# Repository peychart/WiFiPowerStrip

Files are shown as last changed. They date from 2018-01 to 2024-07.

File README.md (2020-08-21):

Wifi Power Strip
================

Software:
---------

C++ source, HTML, Javascript & JSON communication with the web interface.

* Full MQTT: configuration, status and distribution of the schema allowing a device auto-detection in home-assistant,
* Allows to control up to 6 switches per ESP8266 module,
* Also allows controlling multiple outputs with a single switch (tuya power strips),
* Can control up to 12 switches with an additional slave module connected via the serial port,
* allows timers on each output,
* management of single-switch multi-output devices(*),
* allows to disabe the timer of an output by maintaining the action of its corresponding switch for a few seconds (only during its activation in the case of multi-outputs with single-switch - see tuya power strip),
* several configurables SSID,
* high or low value configurable on each output (allowing different interface cards),
* configuration and retrieval of the device status by html requests (JSON format) also available,
* available backup of the output states on reboot,
* firmware update via WiFi (OTA), without loss of setting (except if the version number is modified beforehand),
* can manage contact sensors (with virtual outputs),
* the html interface can be delocalized to a dedicated server,
* dedug trace available in a telnet console (only in the C beta-version),
* each object (wifi manager, pins manager, mqtt or ntp manager) is reusable for other projects...

(*): pressing, for example, the switch 3 times with less than 1 second between each press activates the third output; if the switch is held (at least 3s) on the last press, the time delay (if set on the selected output) will be canceled.

Http requests available:
<table>
  <tr>
    <td><tt>http://IPAddress</tt></td>
    <td>WEB User Interface</td>
  </tr>
  <tr>
    <td><tt>http://IPAddress/status</tt></td>
    <td>get the device state in JSON format - also used by the html interface</td>
  </tr>
  <tr>
    <td><tt>http://IPAddress/status?{'JSON setting'}</tt></td>
    <td>set all or parts of the state setting (see above)</td>
  </tr>
  <tr>
    <td><tt>http://IPAddress/html</tt></td>
    <td>allows the recovery of the HTML code of the interface for the purpose of its delocalization on a dedicated external server.</td>
  </tr>
  <tr>
    <td><tt>http://IPAddress/restart</tt></td>
    <td>restart the device, the output states will be restored.</td>
  </tr>
</table>

TODO:
* set the "Access-Control-Allow-Origin" parameter (to allow a domain name use),
* test the new serial communication with the slave,
* add the trigger setting programmed in the interface,
* finalize the setting of all the mqtt parameters in the interface (default values in setting.h),
* do the dev doc,
* ...

Screenshots:

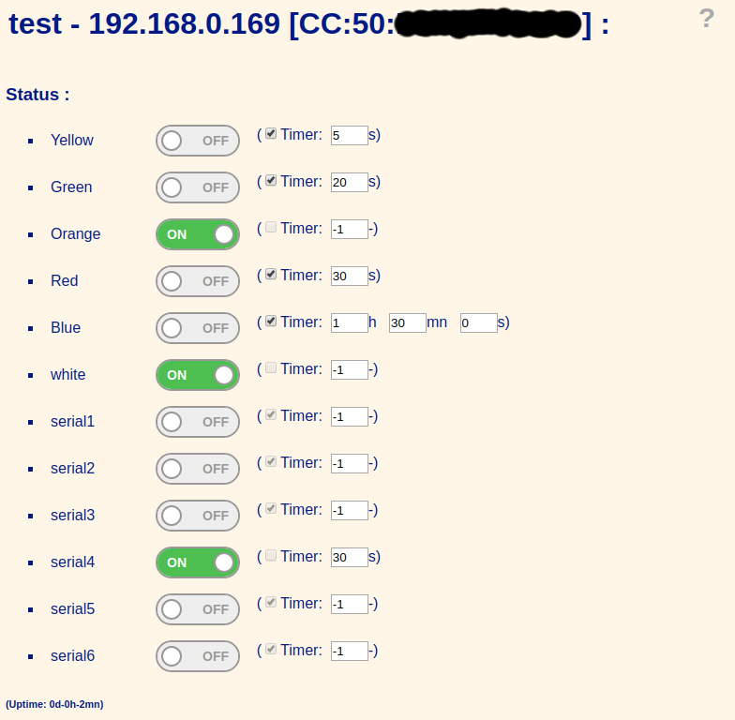
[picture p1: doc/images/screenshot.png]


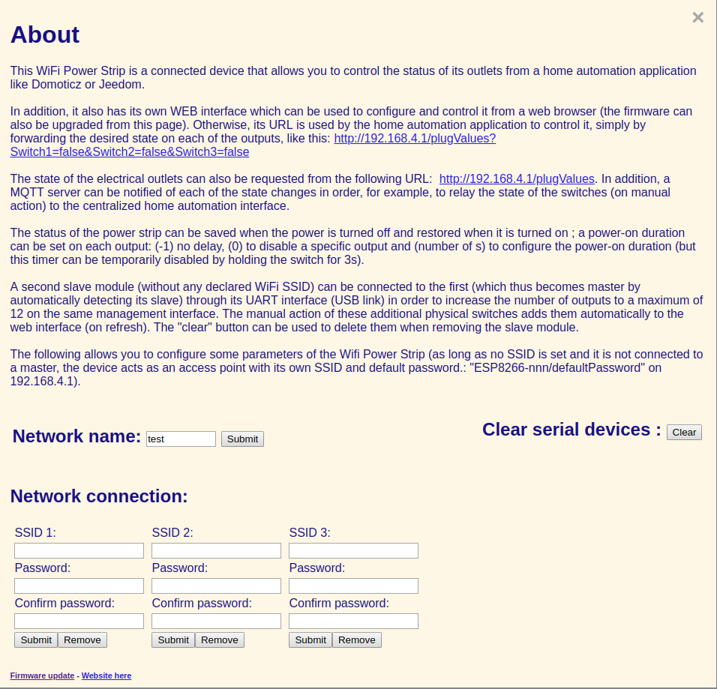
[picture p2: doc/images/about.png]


MQTT parameters:

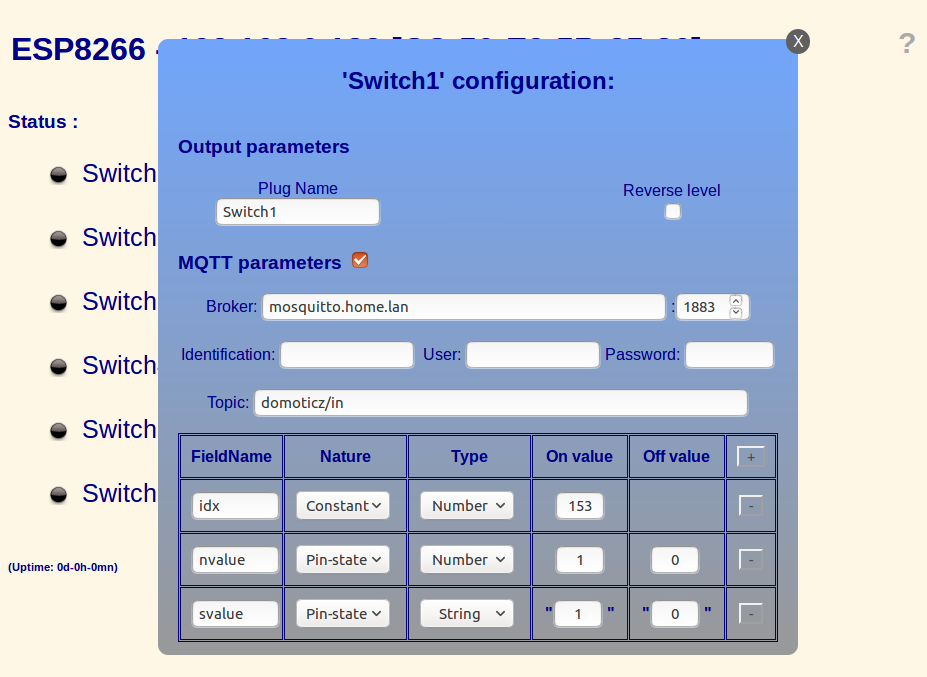
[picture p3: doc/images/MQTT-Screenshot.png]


Hardware:
---------

* Webmos D1 mini + wiring diagram of the interfaces (with 2N7002 or S8050):
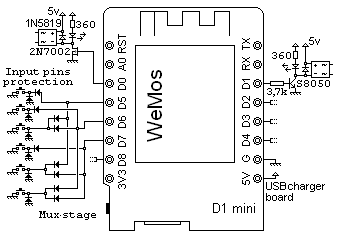
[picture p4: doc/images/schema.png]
* 
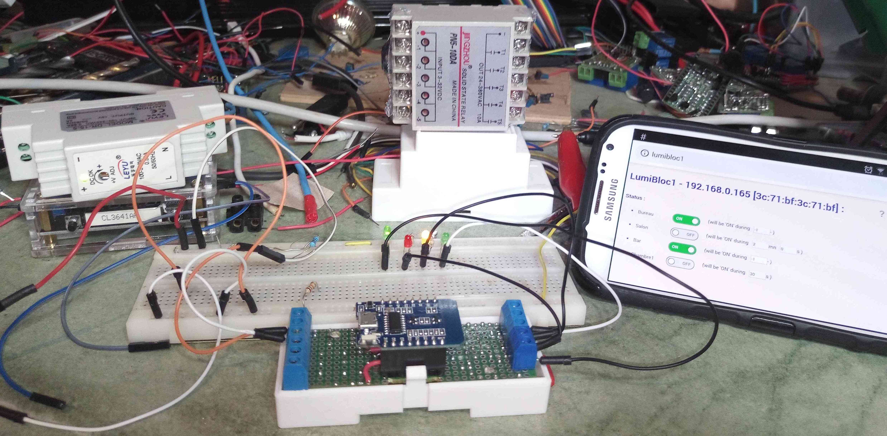
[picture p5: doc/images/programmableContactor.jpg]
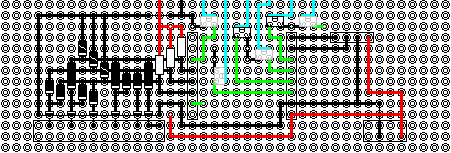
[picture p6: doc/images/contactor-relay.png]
* Progammable contactors with WiFi control:  
* Interface board: 1 x Wemos mini D1, 15 x 1N5819, 3 x Zeners 3.3v, 6 resistors 360 ohms, 6 x MOSFET 2N7002 SOT23 and somes connectors... for each master / slave module (via UART) of 6 inputs and 6 outputs for power interface control (and SSR relay interface or, best to turn off led lights: 5V relay module board, 6 channels).
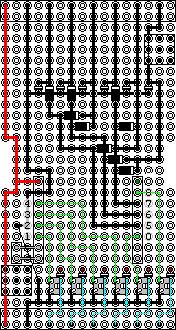
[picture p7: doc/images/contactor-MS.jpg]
* 
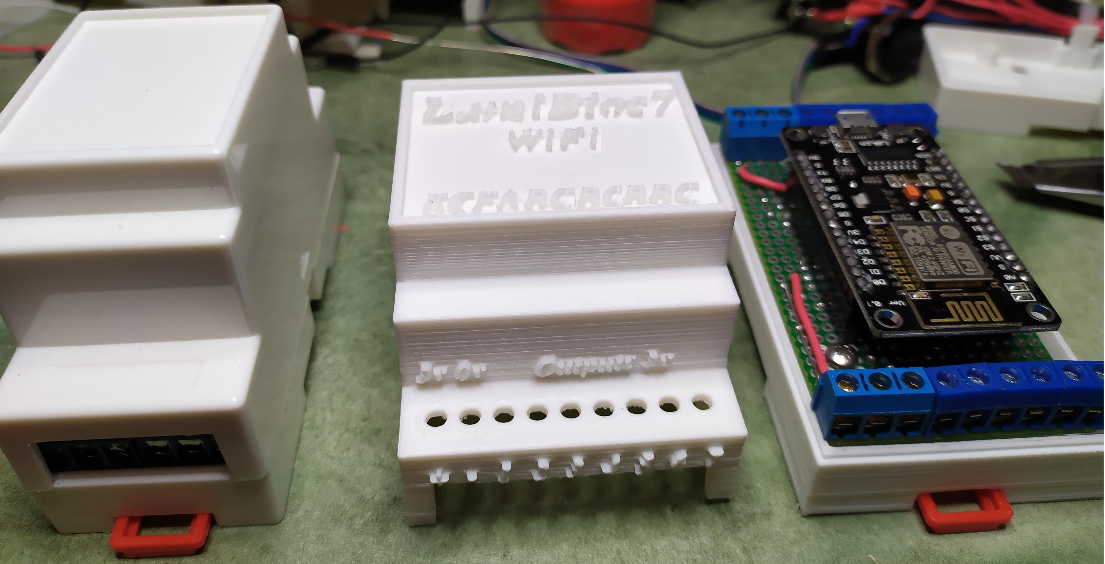
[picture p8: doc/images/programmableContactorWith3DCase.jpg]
* With 3D printed case: 
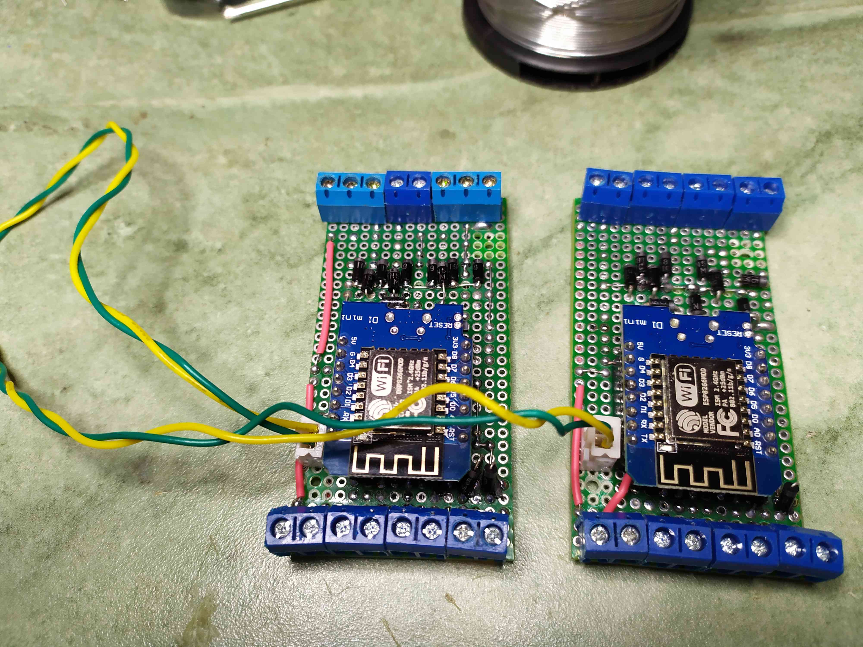
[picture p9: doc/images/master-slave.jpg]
* Master/Slave modules: 
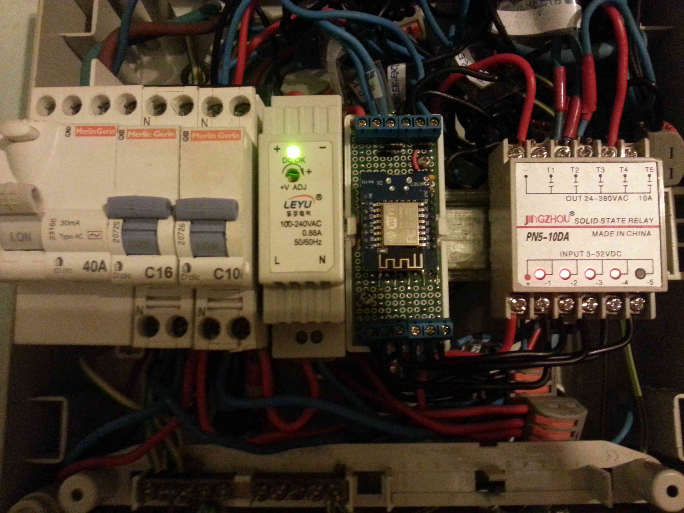
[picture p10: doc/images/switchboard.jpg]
* switchboard (5-way module for lighting control): 
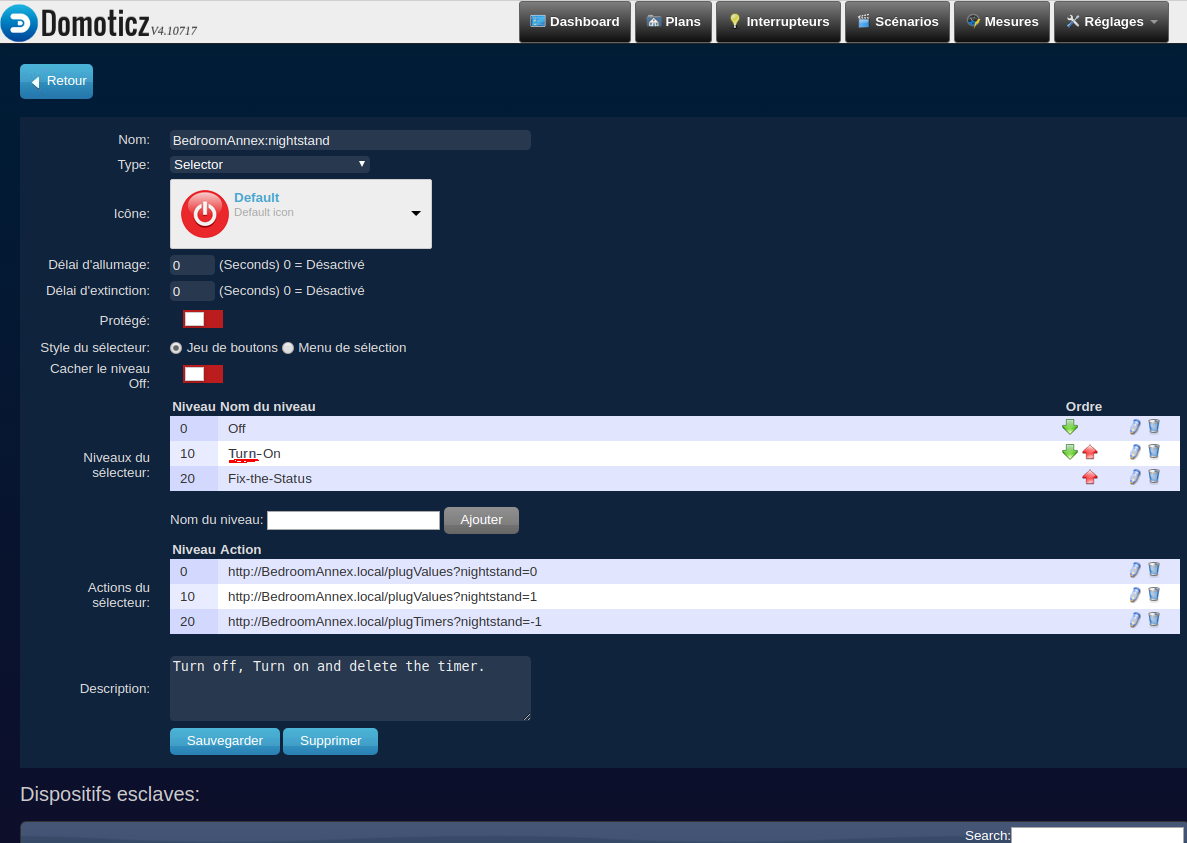
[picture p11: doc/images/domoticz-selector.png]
* Example of selector definition in Domoticz: 
* Plan view ("Fixe-the-State" to inhibit the internal timer, such a 3-second press on switch):
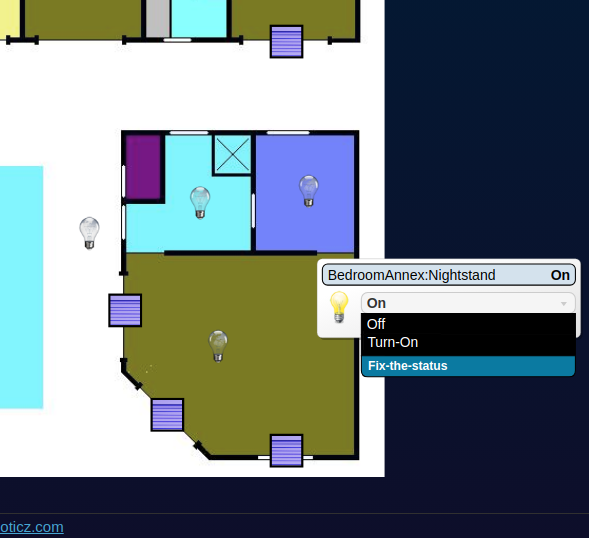
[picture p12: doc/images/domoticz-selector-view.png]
* 
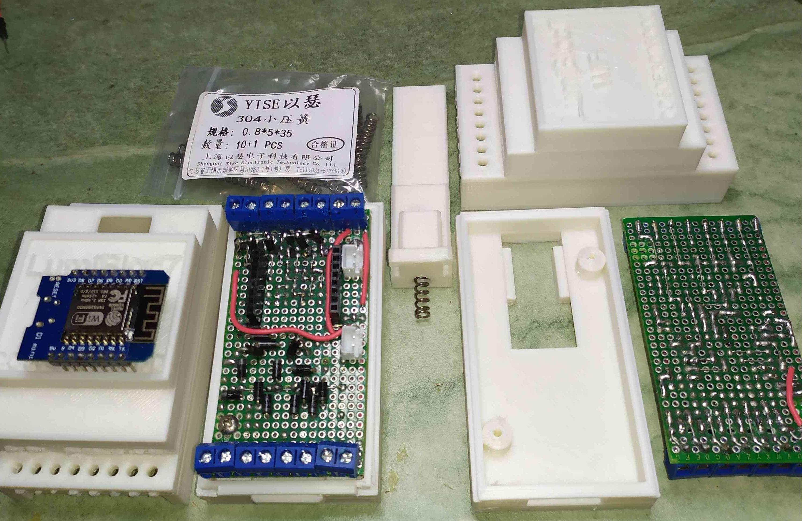
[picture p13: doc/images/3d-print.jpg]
* 

* relay modules (Serial Master/Slave):
* 

* USB WiFi-relay (same code with ESP01-1m):
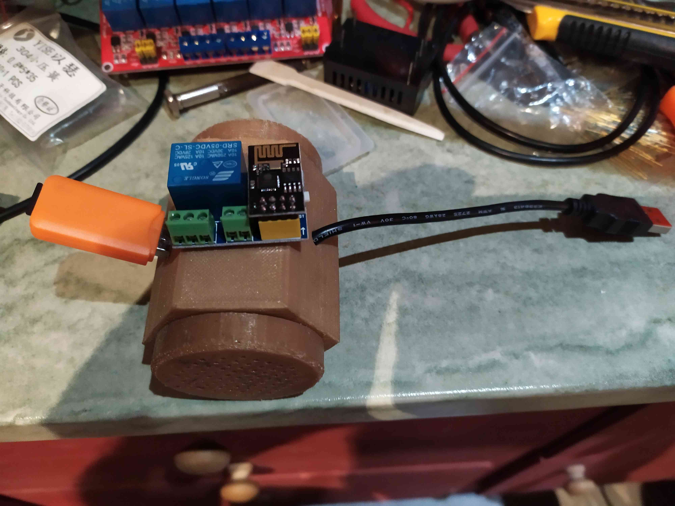
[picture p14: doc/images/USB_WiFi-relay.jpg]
* 

* Hacking - same code on TUYA power strip (TYWE3S):
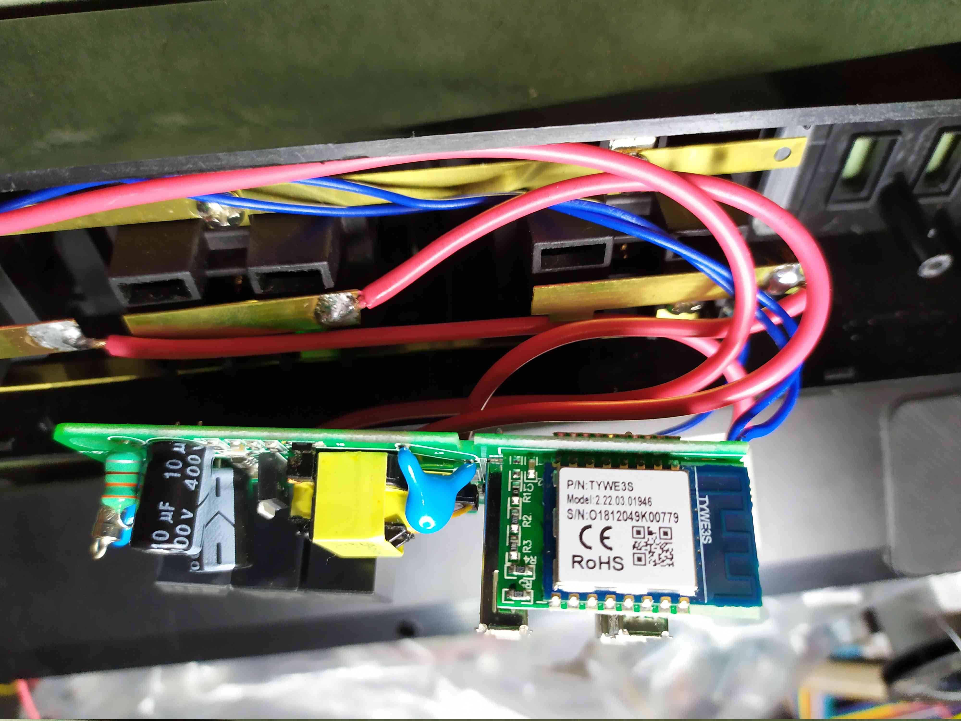
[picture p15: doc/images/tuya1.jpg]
* 
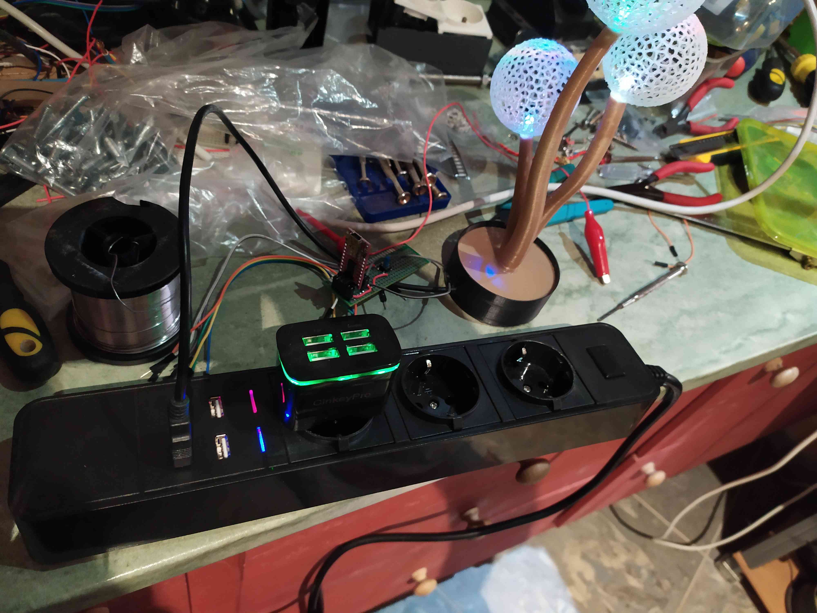
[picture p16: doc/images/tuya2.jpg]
*

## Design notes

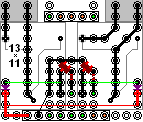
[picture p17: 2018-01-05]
doc/images/module.png

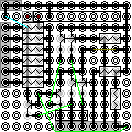
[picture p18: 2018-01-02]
doc/images/switchBoard.png

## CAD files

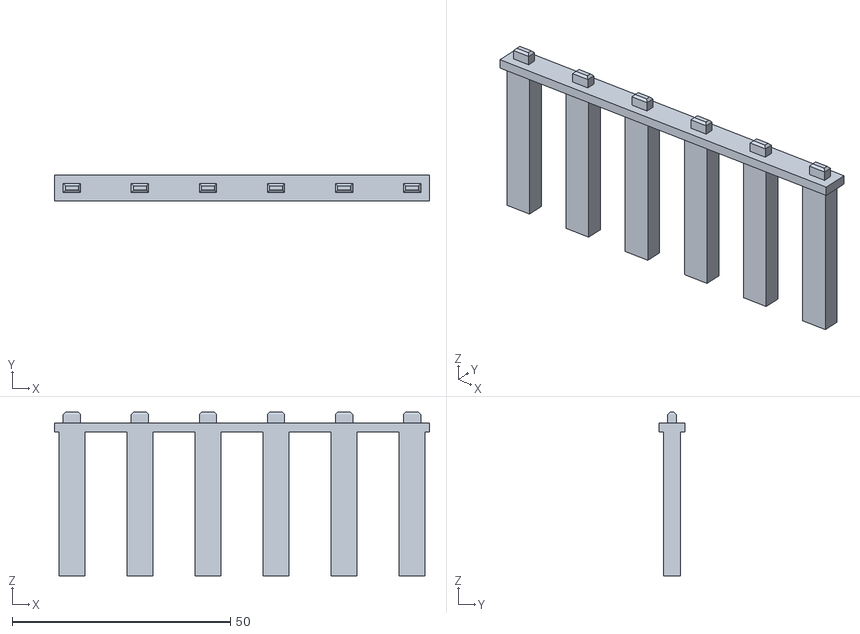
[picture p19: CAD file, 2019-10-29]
3d-templates/Contact-version/leds.stl
86.0 x 6.00 x 37.5

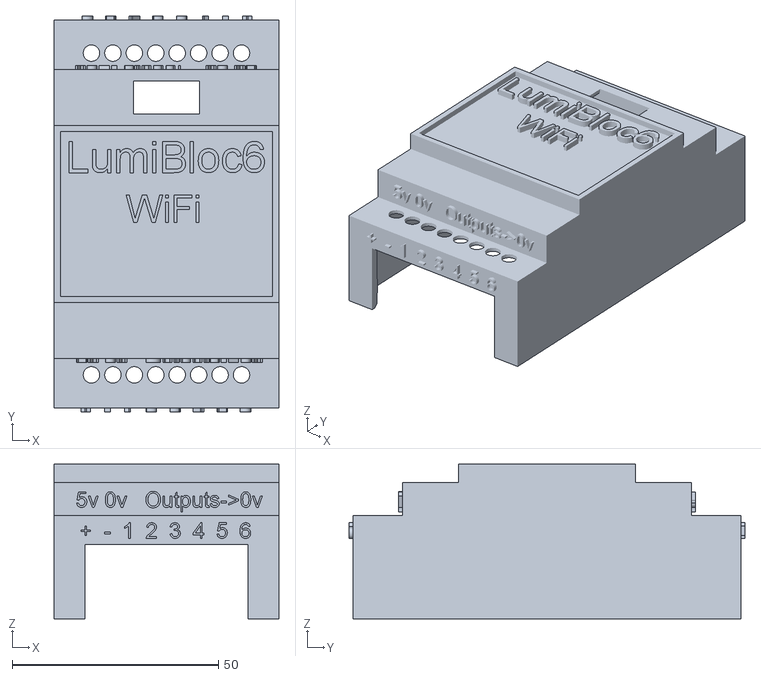
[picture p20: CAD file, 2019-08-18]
3d-templates/SSR-version/lumiCouvercle.stl
54.5 x 96.0 x 37.5

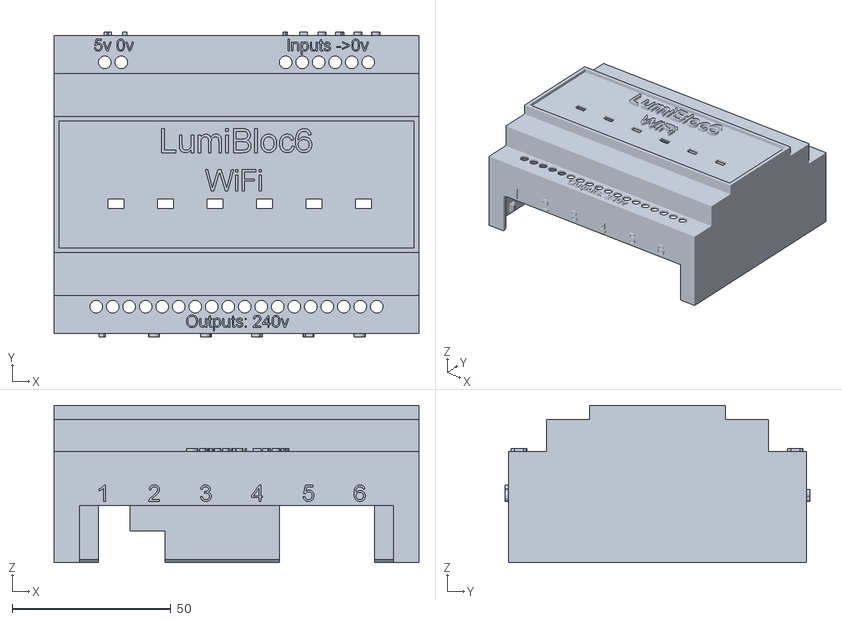
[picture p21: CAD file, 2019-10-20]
3d-templates/Contact-version/relayLid.stl
115.0 x 96.0 x 49.5

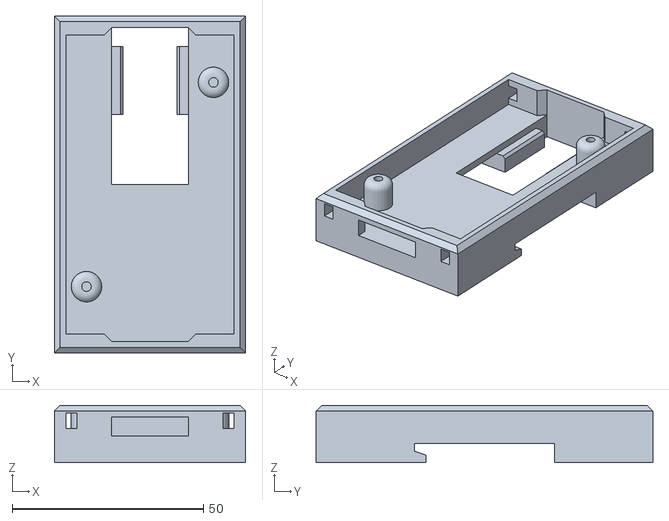
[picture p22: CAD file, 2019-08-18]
3d-templates/SSR-version/lumiBoitier.stl
50.0 x 88.0 x 15.0

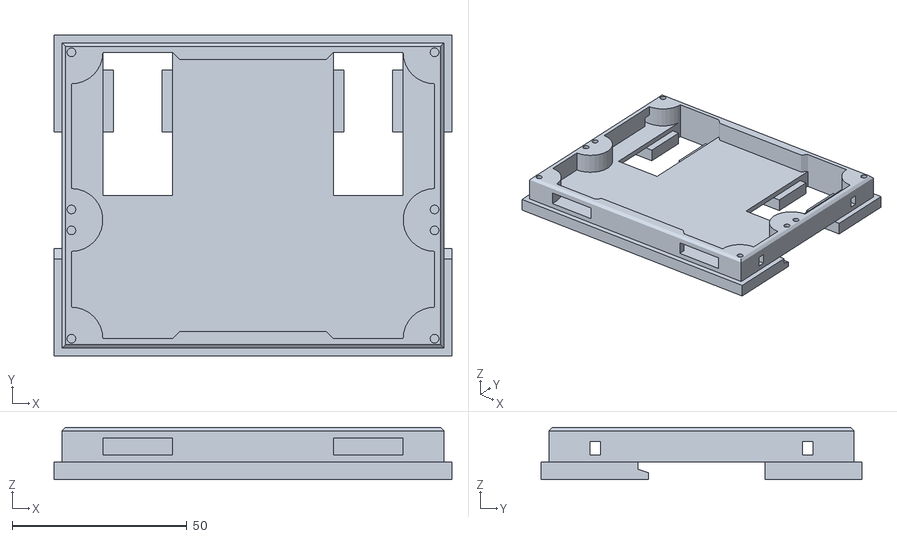
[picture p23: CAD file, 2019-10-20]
3d-templates/Contact-version/relayBox.stl
114.0 x 92.0 x 15.0

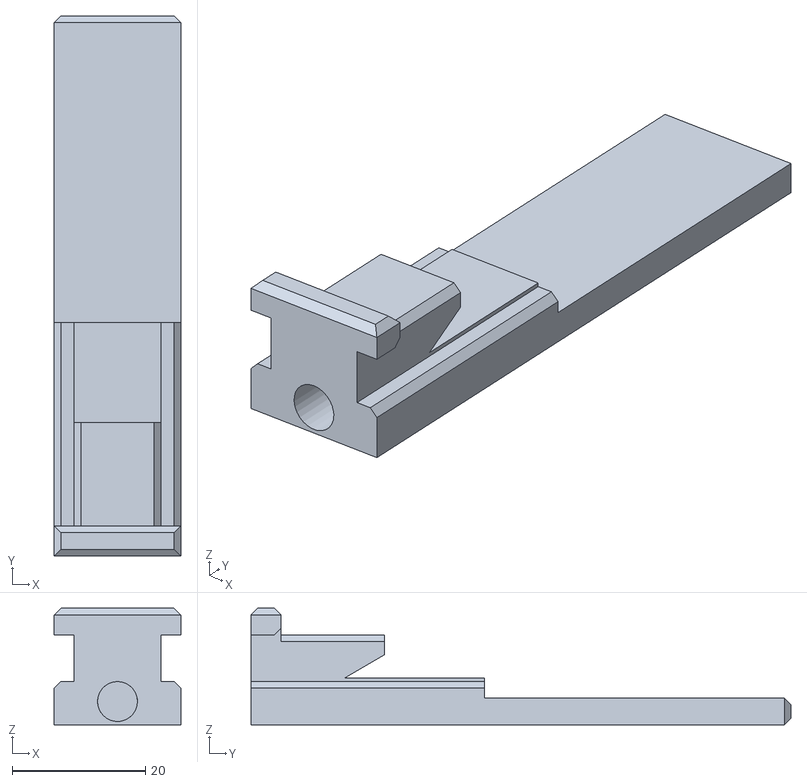
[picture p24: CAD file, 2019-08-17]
3d-templates/SSR-version/lumiCoulisseau.stl
19.0 x 81.0 x 17.5

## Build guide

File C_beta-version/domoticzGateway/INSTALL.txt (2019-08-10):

#!/bin/bash
#This NodeJs application use this lib: http://wiki.sandaysoft.com/a/SteelSeries_Gauges
sudo apt-get update
sudo apt-get upgrade -y
sudo apt-get install -y git wget curl

# Nodejs installation:
sudo wget -O - https://raw.githubusercontent.com/audstanley/NodeJs-Raspberry-Pi/master/Install-Node.sh | bash; node -v;
sudo npm install npm@latest -g

mkdir -p /var/www/domoticzGateway
cd /var/www/domoticzGateway
wget https://raw.githubusercontent.com/peychart/WiFiPowerStrip/master/domoticzGateway/domoticzGateway.js
wget https://raw.githubusercontent.com/peychart/WiFiPowerStrip/master/domoticzGateway/domoticzGateway.service
wget https://raw.githubusercontent.com/peychart/WiFiPowerStrip/master/domoticzGateway/package.json

ln -s /usr/local/bin/node /usr/local/bin/nodejs
sudo npm install
sudo mv domoticzGateway.service /lib/systemd/system
sudo systemctl enable domoticzGateway
sudo systemctl start domoticzGateway

netstat -ant

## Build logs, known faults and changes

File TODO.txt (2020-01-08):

* end of MQTT conf pop-up,
* readConfig()/writeConfig() debugging,
* script configuration encryption,
* serial pins,
* ...

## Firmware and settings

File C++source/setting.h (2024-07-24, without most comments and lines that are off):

#define HEADER_FB360A2A9706121
#define VERSION                  "4.0.0"              //Change this value to reset current config on the next boot...
#define DEFAULTHOSTNAME          "ESP8266"
#define DEFAULTWIFIPASS          "defaultPassword"
#define WIFI_MEMORY_LEAKS         10000UL
#define DEBOUNCE_TIME             25UL                //(ms) <- switches treatments...
#define POST_DEBOUNCE_TIME        500UL               //(ms) <- very bad switches...
#define HOLD_TO_DISABLE_TIMER     3UL                 //(s)  <- switches treatments...
#define CMD_COMPLETED_TIMER       1UL                 //(s)  <- One switch/multi-outputs treatment...
#define ROUTE_VERSION              "version"
#define ROUTE_HOSTNAME             "hostname"
#define ROUTE__DEFAULT_HOSTNAME    "defHName"
#define ROUTE__DEFAULT_PASSWORD    "defWFPwd"
#define ROUTE_CHIP_IDENT           "ident"
#define ROUTE_UPTIME               "uptime"
#define ROUTE_MAC_ADDR             "macAddr"
#define ROUTE_IP_ADDR              "ip"
#define ROUTE_PIN_GPIO             "gpio"
#define ROUTE_PIN_NAME             "name"
#define ROUTE_PIN_STATE            "state"
#define ROUTE_PIN_CMD              "cmd"
#define ROUTE_PIN_VALUE            "timeout"
#define ROUTE_PIN_RESTART          "pinrestart"
#define ROUTE_PIN_ENABLED          "enabled"
#define ROUTE_PIN_MODE             "mode"
#define ROUTE_PIN_REVERSE          "reverse"
#define ROUTE_PIN_HIDDEN           "hidden"
#define ROUTE_PIN_BLINKING         "blinking"
#define ROUTE_PIN_BLINKING_UP      "blinkingUp"
#define ROUTE_PIN_BLINKING_DOWN    "blinkingDown"
#define ROUTE_WIFI_SSID            "ssid"
#define ROUTE_WIFI_PWD             "pwd"
#define ROUTE_NTP_SOURCE           "ntpSource"
#define ROUTE_NTP_ZONE             "ntpZone"
#define ROUTE_NTP_DAYLIGHT         "ntpDayLight"
#define ROUTE_MQTT_BROKER          "mqttBroker"
#define ROUTE_MQTT_PORT            "mqttPort"
#define ROUTE_MQTT_IDENT           "mqttIdent"
#define ROUTE_MQTT_USER            "mqttUser"
#define ROUTE_MQTT_PWD             "mqttPwd"
#define ROUTE_MQTT_PUBTOPIC        "mqttPubTopic"
#define ROUTE_MQTT_SCHEMA          "mqttSchema"
#define ROUTE_HTML_CODE            "html"
#define ROUTE_RESET                "reset"
#define ROUTE_RESTORE              "restoreStateOnBoot"
#define STDSTR(i)                   std::string(String(i,DEC).c_str())
#define G(n)                        String(F(n)).c_str()
#define DEFAULT_MQTT_BROKER        "192.168.0.253"
  #define DEFAULT_MQTT_PORT         1883
  #define DEFAULT_MQTT_IDENT       ""    // WARNING: must be different between devices on a same broker...
  #define DEFAULT_MQTT_USER        ""
  #define DEFAULT_MQTT_PWD         ""
  #define DEFAULT_MQTT_STATE_TOPIC (String(F("home-assistant/")) + String(ESP.getChipId(),DEC) + G("/") + ROUTE_PIN_STATE).c_str()
  #define DEFAULT_MQTT_CMD_TOPIC   (String(F("home-assistant/")) + String(ESP.getChipId(),DEC) + G("/") + ROUTE_PIN_CMD  ).c_str()
  #define MQTT_CONFIG_TOPIC        "config"
  #define PAYLOAD_ON               "on"
  #define PAYLOAD_OFF              "off"
  #define MQTT_SCHEMA(i)            std::map<std::string,untyped>{                                                 \
                                      {"state_topic"  , DEFAULT_MQTT_STATE_TOPIC + STDSTR(i) + G("/" ROUTE_PIN_STATE)  }  \
                                     ,{"command_topic", myMqtt.ident() + STDSTR(i) + G("/" ROUTE_PIN_CMD) }        \
                                     ,{"payload_on"   , G(PAYLOAD_ON)  }                                           \
                                     ,{"payload_off"  , G(PAYLOAD_OFF) }                                           \
                                     ,{"mame"         , myPins(i).name() }                                         \
                                     ,{"retain"       , false }                                                    \
                                     ,{"optimistic"   , false }                                                    \
                                     ,{"device_class" , G(ROUTE_PIN_CMD) }                                      \
                                    }
#ifdef _MAIN_
#define LUMIBLOC_RELAY6X_D1MINI
#ifdef LUMIBLOC_RELAY6X_D1MINI                                                    //relay 6x
#define INPUT_CONFIG F("[\
/*D5*/{\"14\": {\"" ROUTE_PIN_NAME "\": \"input1\" }},\
/*D6*/{\"12\": {\"" ROUTE_PIN_NAME "\": \"input2\" }},\
/*D7*/{\"13\": {\"" ROUTE_PIN_NAME "\": \"input3\" }}\
]")
#define OUTPUT_CONFIG F("[\
/*D8*/{\"15\": {\"" ROUTE_PIN_NAME "\": \"Switch1\", \"" ROUTE_PIN_REVERSE "\": false, \"" ROUTE_PIN_VALUE "\": -1, \"" ROUTE_PIN_STATE "\": false }},\
/*D1*/{ \"5\": {\"" ROUTE_PIN_NAME "\": \"Switch2\", \"" ROUTE_PIN_REVERSE "\": false, \"" ROUTE_PIN_VALUE "\": -1, \"" ROUTE_PIN_STATE "\": false }},\
/*D2*/{ \"4\": {\"" ROUTE_PIN_NAME "\": \"Switch3\", \"" ROUTE_PIN_REVERSE "\": false, \"" ROUTE_PIN_VALUE "\": -1, \"" ROUTE_PIN_STATE "\": false }},\
/*D3*/{ \"0\": {\"" ROUTE_PIN_NAME "\": \"Switch4\", \"" ROUTE_PIN_REVERSE "\": false, \"" ROUTE_PIN_VALUE "\": -1, \"" ROUTE_PIN_STATE "\": false }},\
/*D4*/{ \"2\": {\"" ROUTE_PIN_NAME "\": \"Switch5\", \"" ROUTE_PIN_REVERSE "\": false, \"" ROUTE_PIN_VALUE "\": -1, \"" ROUTE_PIN_STATE "\": false }},\
/*D0*/{\"16\": {\"" ROUTE_PIN_NAME "\": \"Switch6\", \"" ROUTE_PIN_REVERSE "\": false, \"" ROUTE_PIN_VALUE "\": -1, \"" ROUTE_PIN_STATE "\": false }}\
]")
#endif
#ifdef LUMIBLOC_SSR_D1MINI                                                        //lumibloc SSD 6x
#define INPUT_CONFIG F("[\
/*D5*/{\"14\": {\"" ROUTE_PIN_NAME "\": \"input1\" }},\
/*D6*/{\"12\": {\"" ROUTE_PIN_NAME "\": \"input2\" }},\
/*D7*/{\"13\": {\"" ROUTE_PIN_NAME "\": \"input3\" }}\
]")
#define OUTPUT_CONFIG F("[\
/*D1*/{ \"5\": {\"" ROUTE_PIN_NAME "\": \"Switch1\", \"" ROUTE_PIN_REVERSE "\": false, \"" ROUTE_PIN_VALUE "\": -1, \"" ROUTE_PIN_STATE "\": false }},\
/*D2*/{ \"4\": {\"" ROUTE_PIN_NAME "\": \"Switch2\", \"" ROUTE_PIN_REVERSE "\": false, \"" ROUTE_PIN_VALUE "\": -1, \"" ROUTE_PIN_STATE "\": false }},\
/*D3*/{ \"0\": {\"" ROUTE_PIN_NAME "\": \"Switch3\", \"" ROUTE_PIN_REVERSE "\": false, \"" ROUTE_PIN_VALUE "\": -1, \"" ROUTE_PIN_STATE "\": false }},\
/*D4*/{ \"2\": {\"" ROUTE_PIN_NAME "\": \"Switch4\", \"" ROUTE_PIN_REVERSE "\": false, \"" ROUTE_PIN_VALUE "\": -1, \"" ROUTE_PIN_STATE "\": false }},\
/*D0*/{\"16\": {\"" ROUTE_PIN_NAME "\": \"Switch5\", \"" ROUTE_PIN_REVERSE "\": false, \"" ROUTE_PIN_VALUE "\": -1, \"" ROUTE_PIN_STATE "\": false }},\
/*D8*/{\"15\": {\"" ROUTE_PIN_NAME "\": \"Switch6\", \"" ROUTE_PIN_REVERSE "\": false, \"" ROUTE_PIN_VALUE "\": -1, \"" ROUTE_PIN_STATE "\": false }}\
]")
#endif
#ifdef SIMPLESWITCH_ESP01                                                        //ESP-01S relay 1x
#define INPUT_CONFIG F("[\
/*D4*/{\"2\": { \"" ROUTE_PIN_NAME "\": \"input1\", \"mode\": INPUT_PULLUP }}\
]")
#define OUTPUT_CONFIG F("[\
/*D3*/{\"0\": {\"" ROUTE_PIN_NAME "\": \"Switch1\", \"" ROUTE_PIN_REVERSE "\": false, \"" ROUTE_PIN_VALUE "\": -1, \"" ROUTE_PIN_STATE "\": false }}\
]")
#endif
#ifdef POWERSTRIP                                                                //TUYA TYSE3S Power Strip 3x
#define INPUT_CONFIG F("[\
/*D7*/{\"13, \"" ROUTE_PIN_NAME "\": \"input3\"}\
]")
#define OUTPUT_CONFIG F("[\
/*D6*/{\"12\": {\"" ROUTE_PIN_NAME "\": \"Switch1\", \"" ROUTE_PIN_REVERSE "\": false, \"" ROUTE_PIN_VALUE "\": -1, \"" ROUTE_PIN_STATE "\": false }},\
/*D5*/{\"14\": {\"" ROUTE_PIN_NAME "\": \"Switch2\", \"" ROUTE_PIN_REVERSE "\": false, \"" ROUTE_PIN_VALUE "\": -1, \"" ROUTE_PIN_STATE "\": false }},\
/*D8*/{\"15\": {\"" ROUTE_PIN_NAME "\": \"Switch3\", \"" ROUTE_PIN_REVERSE "\": false, \"" ROUTE_PIN_VALUE "\": -1, \"" ROUTE_PIN_STATE "\": false }},\
/*D3*/{ \"0\": {\"" ROUTE_PIN_NAME "\": \"Switch4\", \"" ROUTE_PIN_REVERSE "\": false, \"" ROUTE_PIN_VALUE "\": -1, \"" ROUTE_PIN_STATE "\": false }},\
/*D2*/{ \"4\": {\"" ROUTE_PIN_NAME "\": \"Switch4\", \"" ROUTE_PIN_REVERSE "\": false, \"" ROUTE_PIN_VALUE "\": -1, \"" ROUTE_PIN_STATE "\": false }}\
]")
#define POWER_LED F("[\
",{\"16\": {\"" ROUTE_PIN_NAME "\": \"PowerLed\", \"" ROUTE_PIN_HIDDEN "\": true, \"" ROUTE_PIN_BLINKING "\": true, \"" ROUTE_PIN_BLINKING_UP "\": 1000, \"" ROUTE_PIN_BLINKING_DOWN "\": 0, \"" ROUTE_PIN_STATE "\": true }}\
]")
#define WIFI_STA_LED F("[\
,/*D1*/{ \"5\": {\"" ROUTE_PIN_NAME "\": \"PowerLed\", \"" ROUTE_PIN_HIDDEN "\": true, \"" ROUTE_PIN_BLINKING "\": true, \"" ROUTE_PIN_BLINKING_UP "\": 5000, \"" ROUTE_PIN_BLINKING_DOWN "\": 250, \"" ROUTE_PIN_STATE "\": true }}\
]")
#endif
#ifdef POWERSTRIP2                                                                 //TUYA TYSE3S Power Strip 3x
#define INPUT_CONFIG F("[\
/*D7*/{\"13\": {\"" ROUTE_PIN_NAME "\": \"input3\" }}\
]")
#define OUTPUT_CONFIG F("[\
/*D1*/{ \"5\": {\"" ROUTE_PIN_NAME "\": \"Switch1\", \"" ROUTE_PIN_REVERSE "\": false, \"" ROUTE_PIN_VALUE "\": -1, \"" ROUTE_PIN_STATE "\": false }},\
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

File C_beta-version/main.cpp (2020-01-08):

//Reference: https://www.arduino.cc/en/Reference/HomePage
//See: http://esp8266.github.io/Arduino/versions/2.1.0-rc1/doc/libraries.html
//Librairies et cartes ESP8266 sur IDE Arduino: http://arduino.esp8266.com/stable/package_esp8266com_index.json
//http://arduino-esp8266.readthedocs.io/en/latest/
//JSon lib: see https://github.com/bblanchon/ArduinoJson.git
//peychart@netcourrier.com 20171021
// Licence: GNU v3
#include <string.h>
#include "FS.h"
#include <ESP8266WiFi.h>
#include <ESP8266mDNS.h>
#include <WiFiClient.h>
#include <ESP8266WebServer.h>
#include <ESP8266HTTPUpdateServer.h>
#include <PubSubClient.h>
//#include <Ethernet.h>
#include <uart.h>
#include <vector>

#include "setting.h"   //Can be adjusted according to the project...

//Avoid to change the following:
#define ulong                     long unsigned int
#define INFINY                    60000UL
bool                              powerLedOn(true), wifiLedOn(false);
String                            hostname(DEFAULTHOSTNAME);    //Can be change by interface
String                            ssid[SSIDCount()];            //Identifiants WiFi /Wifi idents
String                            password[SSIDCount()];        //Mots de passe WiFi /Wifi passwords
std::vector<String>              _outputName;
std::vector<ushort>               outputValue, outputReverse;   //No bool/char because of this fucking compilator
static bool                       WiFiAP(false), mustResto(false);
#ifdef DEFAULTWIFIPASS
  static ushort                   nbWifiAttempts(MAXWIFIRETRY), WifiAPTimeout;
#endif
static ulong                      next_reconnect(0UL);
static std::vector<ulong>         maxDuration, timerOn;
volatile short                    intr(0);
volatile ulong                    rebounds_completed(0L);
ulong                             next_timerDisabled(0L);
bool                              slave(false);
static String                     serialInputString;
ESP8266WebServer                  ESPWebServer(80);
ESP8266HTTPUpdateServer           httpUpdater;

WiFiClient                        ethClient;
PubSubClient                      mqttClient(ethClient);
String                            mqttBroker, mqttIdent, mqttUser, mqttPwd, mqttQueue;
ushort                            mqttPort;
std::vector<std::vector<String>>  mqttFieldName, mqttOnValue, mqttOffValue;
std::vector<std::vector<ushort>>  mqttNature, mqttType;
std::vector<ushort>               mqttEnable;

#define Serial_print(m)          {if(Serial) Serial.print(m);}
#define Serial_printf(m,n)       {if(Serial) Serial.printf(m,n);}
#ifdef DEBUG
  WiFiServer                      telnetServer(23);
  WiFiClient                      telnetClient;
  #ifdef DEFAULTWIFIPASS
    #define DEBUG_print(m)       {if(telnetClient && telnetClient.connected()) telnetClient.print(m);    Serial_print(m);}
    #define DEBUG_printf(m,n)    {if(telnetClient && telnetClient.connected()) telnetClient.printf(m,n); Serial_printf(m,n);}
  #else
    #define DEBUG_print(m)        Serial_print(m);
    #define DEBUG_printf(m,n)     Serial_printf(m,n);
  #endif
#else
  #define DEBUG_print(m)          ;
  #define DEBUG_printf(m,n)       ;
#endif

#define WIFI_STA_Connected()     (WiFi.status()==WL_CONNECTED)
#define isMaster()                ssid[0].length()
#define isSlave()                 slave
#define inputCount()             _inputPin.size()
#define outputCount()             (unsigned)atoi(outputName(-1).c_str())
#define clearOutputCount()        outputName(-2)

bool notifyProxy(ushort, String="");
bool readConfig(bool=true);
void writeConfig();

inline bool isNow     (ulong v)  {ulong ms(millis()); return((v<ms) && (ms-v)<INFINY);}  //Because of millis() rollover:
inline void setTimer  (ushort i) {timerOn[i] = ( (maxDuration[i]==(-1UL)) ?maxDuration[i] :(millis() + (1000L*maxDuration[i])) );}
inline void unsetTimer(ushort i) {timerOn[i] = -1UL;}
inline bool isTimer   (ushort i) {return((timerOn[i] != -1UL));}

inline String getHostname()        {return hostname;}

bool addMQTT(ushort i, ushort j){bool isNew(false);
  std::vector<String> s;
  std::vector<ushort> n;
  while(mqttFieldName.size()<=i){isNew=true;
    mqttFieldName.push_back(s);
    mqttNature.push_back(n);
    mqttType.push_back(n);
    mqttOnValue.push_back(s);
    mqttOffValue.push_back(s);
  }while(mqttFieldName[i].size()<=j){isNew=true;
    mqttFieldName[i].push_back("");mqttNature[i].push_back(0);mqttType[i].push_back(0);mqttOnValue[i].push_back("");mqttOffValue[i].push_back("");
  }return isNew;
}

void addSwitch(){
  ushort i(_outputName.size());
  if(!i){
    _outputName.reserve(i); outputValue.reserve(i); maxDuration.reserve(i); timerOn.reserve(i);
    mqttFieldName.reserve(i); mqttNature.reserve(i); mqttType.reserve(i); mqttOnValue.reserve(i); mqttOffValue.reserve(i);
  };if(i<_outputPin.size())
        _outputName.push_back("Switch" + String(i+1, DEC));
  else  _outputName.push_back("Serial" + String(i-_outputPin.size()+1, DEC));
  outputValue.push_back(0);
  outputReverse.push_back((ushort)REVERSE_OUTPUT);
  maxDuration.push_back(-1UL);
  timerOn.push_back(-1UL);
  mqttEnable.push_back(0);
}

String& outputName(ushort n){
  static ushort serialPinCount(0);
  static String pinCount;
  if(n >= ushort(-2)){                                            //return count
    if(n==ushort(-2)) serialPinCount=0;                           //clear serial pins
    return(pinCount=(_outputPin.size()+serialPinCount));
  }
  if(n>=_outputPin.size()+serialPinCount){
    for(ushort i=_outputPin.size()+serialPinCount; i<=n; i++){    //New serial pin(s)
      addSwitch();
      DEBUG_print("SerialPin '" + _outputName[i] + "' created.\n");
    }serialPinCount=n-_outputPin.size()+1;
  }return(_outputName[n]);
}

#define WEB_S(n) ESPWebServer.sendContent(n)
#define WEB_F(n) ESPWebServer.sendContent(F(n))
void sendHTML_input(String name, String type, String more){
  WEB_S( "<input"+ (name.length() ?(" id='" + name + "' name='" + name + "'") : String("")) + " type='" + type + (more.length()?"' ":"'") + more + ">\n" );
}void sendHTML_inputText   (String name, String val, String more=""){sendHTML_input(name, F("text"),    "value='" + val + (more.length()?"' ":"'") + more);}
void  sendHTML_inputPwd    (String name, String val, String more=""){sendHTML_input(name, F("password"),"value='" + val + (more.length()?"' ":"'") + more);}
void  sendHTML_inputNumber (String name, String val, String more=""){sendHTML_input(name, F("number"),  "value='" + val + (more.length()?"' ":"'") + more);}
void  sendHTML_checkbox    (String name, bool   val, String more=""){sendHTML_input(name, F("checkbox"), more + (val ?" checked" :""));}
void  sendHTML_button      (String name, String val, String more=""){sendHTML_input(name, F("button"),  "value='" + val + (more.length()?"' ":"'") + more);}
void  sendHTML_optionSelect(String lib,  String val, String more=""){WEB_S("<option value='" + val + (more.length()?"' ":"'") + more + ">" + lib + "</option>\n");}

void sendHTML(bool blankPage=false){
  ESPWebServer.setContentLength(CONTENT_LENGTH_UNKNOWN);
  ESPWebServer.send(200, "text/html", F("<!DOCTYPE HTML>\n<html lang='us-US'>\n<head><meta charset='utf-8'/>\n"));
  if(!blankPage){
    WEB_F("<title>");
    WEB_S(getHostname());
    WEB_F("</title>\n\
<style>\n\
body{background-color: #fff7e6;font-family: Arial,Helvetica,Sans-Serif;Color: #000088;}\n\
 .modal {display: none;position: fixed;z-index: 1;left: 0%;top: 0%;height: 100%;width: 100%;overflow: scroll;background-color: #000000;}\n\
 .modal-content {background-color: #fff7e6;margin: 5% auto;padding: 15px;border: 2px solid #888;height: 90%;width: 90%;min-height: 755px;}\n\
 .close {color: #aaa;float: right;font-size: 30px;font-weight: bold;}\n\
 td.switches {text-align: left;min-height: 60px;vertical-align: middle;display: inline-block;overflow: hidden;text-overflow: ellipsis;white-space: nowrap;}\n\
 .bulle {border: none;height: 20px;width: 20px;cursor: pointer;background-repeat: no-repeat;background: transparent;background-position: center;vertical-align: center;background-image:url('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');}\n\
 .outputName {width: 150px;font-size: 25px;color: #000088;border: none;background: transparent;}\n\
 .delayConf {float: left;vertical-align: middle;display: inline-block;overflow: hidden;text-overflow: ellipsis;white-space: nowrap;}\n\
 .duration {width: 50px;} .sDuration {width: 50px;}\n\
/*see: https://proto.io/freebies/onoff/: */\n\
 .onoffswitch {position: relative;width: 90px;-webkit-user-select: none;-moz-user-select: none;-ms-user-select: none;}\n\
 .onoffswitch-checkbox {display: none;}\n\
 .onoffswitch-label {display: block;overflow: hidden;cursor: pointer;border: 2px solid #999999;border-radius: 20px;}\n\
 .onoffswitch-inner {display: block;width: 200%;margin-left: -100%;transition: margin 0.3s ease-in 0s;}\n\
 .onoffswitch-inner:before, .onoffswitch-inner:after {display: block;float: left;width: 50%;height: 30px;padding: 0;line-height: 30px;font-size: 14px;color: white;font-family: Trebuchet, Arial, sans-serif;font-weight: bold;box-sizing: border-box;}\n\
 .onoffswitch-inner:before{content: 'ON';padding-left: 10px;background-color: #34C247;color: #FFFFFF;}\n\
 .onoffswitch-inner:after {content: 'OFF';padding-right: 10px;background-color: #EEEEEE;color: #999999;text-align: right;}\n\
 .onoffswitch-switch{display: block;width: 18px;margin: 6px;background: #FFFFFF;position: absolute;top: 0;bottom: 0;right: 56px;border: 2px solid #999999;border-radius: 20px;transition: all 0.3s ease-in 0s;}\n\
 .onoffswitch-checkbox:checked + .onoffswitch-label .onoffswitch-inner {margin-left: 0;}\n\
 .onoffswitch-checkbox:checked + .onoffswitch-label .onoffswitch-switch {right: 0px;}\n\
 .onofftimer {right: 0px;vertical-align: middle;}\n\
 .confPopup {position: relative;opacity: 0;display: none;-webkit-transition: opacity 400ms ease-in;-moz-transition: opacity 400ms ease-in;transition: opacity 400ms ease-in;}\n\
 .confPopup:target {opacity: 1;display: block;}\n\
 .confPopup > div {width: 600px;position: fixed;top: 25px;left: 25px;margin: 10% auto;padding: 5px 20px 13px 20px;border-radius: 10px;background: #71a6fc;background: -moz-linear-gradient(#71a6fc, #fff);background: -webkit-linear-gradient(#71a6fc, #999);}\n\
 .closeconfPopup {background: #606061;color: #FFFFFF;line-height: 25px;position: absolute;right: -12px;text-align: center;top: -10px;width: 24px;text-decoration: none;-webkit-border-radius: 12px;-moz-box-shadow: 1px 1px 3px #000;}\n\
 .closeconfPopup:hover {background: #00d9ff;}\n\
</style></head>\n");
  }if(blankPage){
    WEB_F("<body>\n");
  }else{
    WEB_F("<body onload='init();'>\n\
<div id='about' class='modal'><div class='modal-content'><span class='close' onClick='refresh();'>&times;</span><h1>About</h1>\
This WiFi Power Strip is a connected device that allows you to control the status of its outlets from a home automation application like Domoticz or Jeedom.<br><br>\
In addition, it also has its own WEB interface which can be used to configure and control it from a web browser (the firmware can also be upgraded from this page). \
Otherwise, its URL is used by the home automation application to control it, simply by forwarding the desired state on each of the outputs, like this:\
<a id='example1' style='padding:0 0 0 5px;'></a><br><br>\
The state of the electrical outlets can also be requested from the following URL: <a id='example2' style='padding:0 0 0 5px;'></a>.\
 In addition, a MQTT server can be notified of each of the state changes in order, for example, to relay the state of the switches (on manual action) to the centralized home automation interface.<br><br>\
The status of the power strip can be saved when the power is turned off and restored when it is turned on ; a power-on duration can be set on each output: (-1) no delay, (0) to disable a specific output and (number of s) to configure the power-on duration (but this timer can be temporarily disabled by holding the switch for 3s).<br><br>\
A second slave module (without any declared WiFi SSID) can be connected to the first (which thus becomes master by automatically detecting its slave) through its UART interface (USB link) in order to increase the number of outputs to a maximum of 12 on the same management interface. \
The manual action of these additional physical switches adds them automatically to the web interface (on refresh). The \"clear\" button can be used to delete them when removing the slave module.<br><br>\
The following allows you to configure some parameters of the Wifi Power Strip (as long as no SSID is set and it is not connected to a master, the device acts as an access point with its own SSID and default password.: \"");
    WEB_S(String(DEFAULTHOSTNAME)); WEB_F("-nnn/");
#ifdef DEFAULTWIFIPASS
    WEB_S(String(DEFAULTWIFIPASS).length() ?F(DEFAULTWIFIPASS) :F("none"));
#else
    WEB_F("none");
#endif
    WEB_F("\" on 192.168.4.1).<br><br>\n<table style='width:100%'><tr style='white-space:nowrap;'><td style='text-align:left;vertical-align:top;'>\n<form method='POST'>\n<h3>Network name: ");
    sendHTML_inputText(F("hostname"), getHostname(), "size='10'");
    sendHTML_button("", F("Submit"), F("onclick='submit();'"));
    WEB_F("</h3></form>\n</td><td style='text-align:right;vertical-align:top;'>\n<form method='POST'><h3>Clear serial devices : ");
    sendHTML_button(F("Clear"), F("Clear"), F("onclick='submit();'")); sendHTML_checkbox("clear", true, "style=\"display:none\"");
    WEB_F("</h3>");
//    sendHTML_checkbox(F("Reboot"), false, F("checked style='display:none;'"));
    WEB_F("&nbsp;</form>\n</td></tr>\n</table>\n<h3>Network connection [");
    WEB_S(WiFi.macAddress());
    WEB_F("]:</h3><table><tr>");
    for(ushort i(0); i<SSIDCount(); i++){
      WEB_F("<td>\n<form method='POST'><table>\n<tr><td>SSID ");
      WEB_S(String(i+1, DEC));
      WEB_F(":</td></tr>\n<tr><td><input type='text' name='SSID' value='");
      WEB_S(ssid[i] + (ssid[i].length() ?F("' readonly><br>\n"): F("'></td></tr>\n")));
      WEB_F("<tr><td>Password:</td></tr>\n<tr><td><input type='password' name='password' value='");
      if(password[i].length()) WEB_S(password[i]);
      WEB_F("'></td></tr>\n<tr><td>Confirm password:</td></tr>\n<tr><td><input type='password' name='confirm' value='");
      if(password[i].length()) WEB_S(password[i]);
      WEB_F("'></td></tr>\n<tr><td><input type='button' value='Submit' onclick='saveSSID(this);'><input type='button' value='Remove' onclick='deleteSSID(this);'></td></tr>\n</table></form>\n</td>\n");
    }WEB_F("</tr></table>\n\
<h6><a href='update' onclick='javascript:event.target.port=80'>Firmware update</a> - <a href='https://github.com/peychart/wifiPowerStrip'>Website here</a></h6>\n\
</div></div>\n");
//                             -----------------------------------------------------------------
    WEB_F("\n<!MAIN FORM>\n<table id='main' style='width:100%'><tr style='height:75px;'>\n<td style='width:800px;'><h1>");
    WEB_S(getHostname()); WEB_F(" - ");WEB_S(WiFiAP ?WiFi.softAPIP().toString() :WiFi.localIP().toString()); WEB_F(" ["); WEB_S(WiFi.macAddress());
    WEB_F("]</h1></td>\n<td style='text-align:right;vertical-align:top;'><div style='text-align:right;white-space: nowrap;'><p><span class='close' onclick='showHelp();'>?</span></p></div></td>\n");
    WEB_F("</tr></table>\n<h3>Status :</h3>\n<table style='width:100%'>\n");
    for (ushort i=0; i<outputCount(); i++){ bool display;
      //Bullet:
      WEB_F("<tr><td class='switches'><form method='POST'><table>\n<!");
      WEB_S(outputName(i));
      WEB_F(":><tr>\n<td style='width:30px;'></td>\n<td style='width:30px;'><div><button id='");
      WEB_S(String(i, DEC));
      WEB_F("' class='bulle' title=\"'");
      WEB_S(outputName(i));
      WEB_F("' configuration\" onclick='initConfPopup(this);'></button></div></td>\n");
      // Tittle:
      //WEB_S(outputName(i));
      WEB_F("<td style='width:150px;'><div class='outputName'>");
      WEB_S(outputName(i));
      WEB_F("</div></td>\n");
      // Switch:
      WEB_F("<td><div class='onoffswitch delayConf'>\n");
      sendHTML_checkbox(outputName(i), outputValue[i], F("class='onoffswitch-checkbox' onClick='switchSubmit(this);'"));
      WEB_F("<label class='onoffswitch-label' for='");
      WEB_S(outputName(i));
      WEB_F("'><span class='onoffswitch-inner'></span><span class='onoffswitch-switch'></span></label>\n</div>\n<div class='delayConf'>&nbsp;&nbsp;&nbsp;\n");
      //Timer:
      WEB_F("(Timer&nbsp;");
      WEB_F("<input type='checkbox' name='");
      WEB_S(outputName(i));
      WEB_F("-timer' ");
      WEB_S((outputValue[i] || ((signed)maxDuration[i]==(-1L))) ?F("uncheck"): F("checked"));
      if((signed)maxDuration[i]==(-1L) || !maxDuration[i]) WEB_F(" disabled");
      WEB_F(" class='onofftimer'>:&nbsp;\n");
      // Days duration:
      display=( (signed)maxDuration[i]!=(-1L) && (maxDuration[i]/86400L)>0L );
      WEB_F("<input type='number' name='"); WEB_S(outputName(i)); WEB_F("-max-duration-d' value='"); WEB_S(String(display ?(maxDuration[i]/86400L) :0L, DEC));
      WEB_F("' min='0' max='31' data-unit=86400 class='duration' style='width:60px;display:");
      WEB_S(display ?F("inline-block") :F("none")); WEB_F(";' onChange='checkDelay(this);'>"); WEB_S(display ?F("d &nbsp;\n") :F("\n"));
      // Hours duration:
      display|=( (signed)maxDuration[i]!=(-1L) && (maxDuration[i]%86400L/3600L)>0L );
      WEB_F("<input type='number' name='"); WEB_S(outputName(i)); WEB_F("-max-duration-h' value='"); WEB_S(String(display ?(maxDuration[i]%86400L/3600L) :0L, DEC));
      WEB_F("' min='0' max='24' data-unit=3600 class='duration' style='display:");
      WEB_S(display ?F("inline-block") :F("none"));
      WEB_F(";' onChange='checkDelay(this);'>");
      WEB_S(display ?F("h &nbsp;\n") :F("\n"));
      // Minutes duration:
      display|=( (signed)maxDuration[i]!=(-1L) && (maxDuration[i]%86400L%3600L/60L)>0L );
      WEB_S("<input type='number' name='"); WEB_S(outputName(i)); WEB_S("-max-duration-mn' value='"); WEB_S(String(display ?(maxDuration[i]%86400L%3600L/60L) :0L, DEC));
      WEB_F("' min='0' max='60' data-unit=60 class='duration' style='display:");
      WEB_S(display ?F("inline-block") :F("none"));
      WEB_F(";' onChange='checkDelay(this);'>"); WEB_S(display ?F("mn &nbsp;\n") :F("\n"));
      // Secondes duration:
      WEB_F("<input type='number' name='"); WEB_S(outputName(i)); WEB_F("-max-duration-s' value='");
      WEB_S( ((signed)maxDuration[i]!=(-1L)) ? String(maxDuration[i]%86400L%3600L%60L, DEC) : String(-1L, DEC) );
      WEB_F("' min='-1' max='60' data-unit=1 class='duration sDuration' onChange='checkDelay(this);'>");
      WEB_S( ((signed)maxDuration[i]!=(-1L)) ?F("s") :F("-") );
      WEB_F(")</div>\n</td></tr>\n</table><div style='display: none;'>\n");
      sendHTML_checkbox("newValue"+String(i, DEC), true);
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
void loop(){
  ESPWebServer.handleClient(); delay(1L);

  connectionTreatment();                //WiFi watcher
  interruptTreatment();                 //Gestion des switchs/Switchs management
  timersTreatment();                    //Timers control

  mySerialEvent();                      //Serial communication for Slave messages traitement
  BlinkingLED();
}
// ***********************************************************************************************

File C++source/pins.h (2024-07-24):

/* ESP8266-pins-Manager C++ (Version 0.1 - 2020/07)
    <https://github.com/peychart/WiFiPowerStrip>

    Copyright (C) 2020  -  peychart

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
    Details of this licence are available online under:
                        http://www.gnu.org/licenses/gpl-3.0.html
*/
/********************************* Serial pins Management ***********************************
  On the naster, the value of a serial gpio must be : (-1) * ( physicalSlaveGpioValue + 1 ).
  Examples:
    gpio 16 on slave is -17 on it's master,
    gpio  0 on slave is  -1 on it's master...
  Serial codes:
    From the master() to the slave():
      - "Sg:0" --> gpio(g) must be FLASE on slave and new state return
      - "Sg:1" --> gpio(g) must be TRUE  on slave and new state return
      - "sg:0" --> gpio(g) must be FALSE on slave in optimistic mode
      - "sg:1" --> gpio(g) must be TRUE  on slave in optimistic mode
      - "S:??" --> slave() must reboot.
    From the slave() to the master():
      - "M:??" --> ask for a master,
      - "Mg:1" --> the new state of gpio(g) is now: TRUE 
      - "Mg:0" --> the new state of gpio(g) is now: FALSE 
      - "Mg:-" --> the timeout of gpio(g) must be disabled.
********************************************************************************************/
#ifndef HEADER_FB360F1A9606491
#define HEADER_FB360F1A9606491

#include <Arduino.h>
#include <LittleFS.h>
#include "untyped.h"

#include "setting.h"
#include "debug.h"

// Json name attributes:
#ifndef ROUTE_PIN_NAME
  #define ROUTE_PIN_NAME           "name"
  #define ROUTE_PIN_GPIO           "gpio"
  #define ROUTE_PIN_MODE           "mode"
  #define ROUTE_PIN_STATE          "state"
  #define ROUTE_PIN_REVERSE        "reverse"
  #define ROUTE_PIN_HIDDEN         "hidden"
  #define ROUTE_PIN_VALUE          "timeout"
  #define ROUTE_PIN_ENABLED        "enabled"
  #define ROUTE_PIN_BLINKING       "blinking"
  #define ROUTE_PIN_BLINKING_UP    "blinkup"
  #define ROUTE_PIN_BLINKING_DOWN  "blinkdown"
  #define ROUTE_RESTORE            "restoreOnBoot"
#endif

#ifndef G
#define G(n)                       String(F(n)).c_str()
#endif

namespace Pins {  static bool _master(false), _slave(false);
  class pin : public untyped {
    public:
      pin(short =-32768);
      virtual ~pin(){};

      inline pin&         name                  ( std::string s )    {if(_isActive()) {_changed|=(name()!=s);    at(G(ROUTE_PIN_NAME))=s;} return *this;};
      inline std::string  name                  ( void )             {return at(G(ROUTE_PIN_NAME)).c_str();};

      inline pin&         gpio                  ( short v )          {if(gpio()==-32768) {_changed|=(gpio()!=v); at(G(ROUTE_PIN_GPIO))=v;} return *this;};
      inline short        gpio                  ( void )             {return at(G(ROUTE_PIN_GPIO));};

      inline pin&         mode                  ( ushort m )         {if(_isActive()) {_changed|=(mode()!=m); pinMode( gpio(), (at(G(ROUTE_PIN_MODE))=m) );} return *this;};
      inline byte         mode                  ( void )             {return( at(G(ROUTE_PIN_MODE)) );};
      inline bool         inputMode             ( void )             {return( !outputMode() );};
      inline bool         outputMode            ( void )             {return( mode()==OUTPUT );};
      bool                isVirtual             ( void )             {return( gpio()<0 );};

      inline pin&         reverse               ( bool v )           {if(outputMode()) {_changed|=(reverse()!=v); at(G(ROUTE_PIN_REVERSE))=  v;} return *this;};
      inline bool         reverse               ( void )             {return at(G(ROUTE_PIN_REVERSE));};
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

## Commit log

2019-04-21 Use millis() sparingly to avoid the exception error...
    [main.cpp]
2019-04-22 Allows adjustment of timers by HTML queries.
2019-04-23 Interrupt optimisation...
2019-04-23 Use delay() sparingly to avoid the exception error...
    [main.cpp]
2019-04-28 Wifi memory leaks (restart while waiting to find the cause)...
    [main.cpp]
2019-07-11 better interrupt treatment.
2019-07-15 disable timeout on switchs after 3s...
2019-07-28 Master/Slave modules via UART...
2019-07-30 Better timer...
2019-08-02 Master/Slave modules and dynamic config of serial switchs...
2019-08-07 Master/Slave modules and dynamic config of serial switches...
2019-08-15 The 3d impression templates...
    [lumiBoitier.stl, lumiCoulisseau.stl, lumiCouvercle.stl]
2019-10-16 Now allows virtual outputs - GPIO=-1 (for contact sensors)...
2019-10-16 Now, virtual outputs are allowed: GPIO=-1 (contact sensors)...
2019-10-18 limit wait on DISABLESWITCHTIMEOUT (for contact sensors)...
2019-10-31 limits waiting on DISABLESWITCHTIMEOUT (for use in contact sensors - opening of door/window
2019-12-11 Allows now only one input (powerStrips control)
2022-06-16 Revert "Update pins.cpp"
    This reverts commit 0dfe93c889f068c9b80e294d42774e00ad7a4f8c.
    [pins.cpp]
2022-06-16 Revert "Update main.cpp"
    This reverts commit ee744c2f4826846650d445906c93091e13112bcd.
    [main.cpp]

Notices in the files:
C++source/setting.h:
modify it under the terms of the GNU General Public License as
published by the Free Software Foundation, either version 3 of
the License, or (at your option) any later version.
